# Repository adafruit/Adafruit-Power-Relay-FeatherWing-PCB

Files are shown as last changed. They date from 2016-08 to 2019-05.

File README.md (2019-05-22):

## Adafruit Power Relay FeatherWing PCB
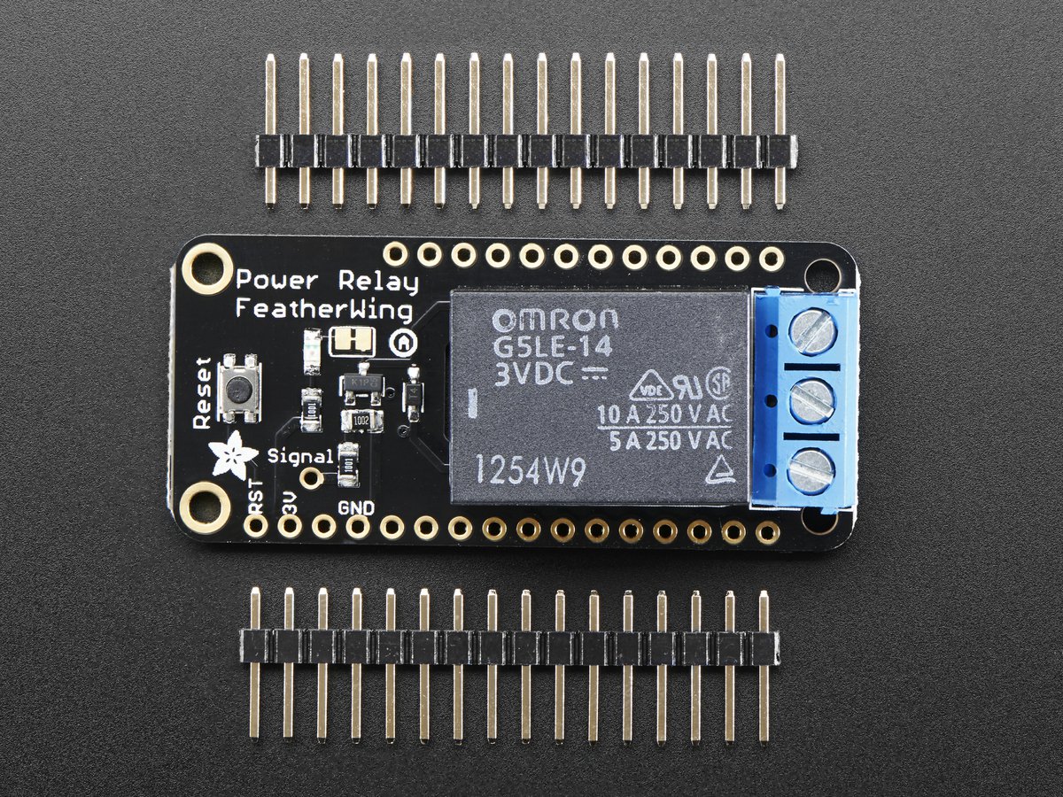
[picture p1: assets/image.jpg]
<a href="http://www.adafruit.com/products/3191"><br/>
Click here to purchase one from the Adafruit shop</a>

This is the Power Relay FeatherWing. It gives you power to control, and control over power. Put simply, you can now turn on and off lamps, fans, solenoids, and other small appliances that run on up to 250VAC or DC power using any Feather board. Compared to our smaller Relay FeatherWings, this one can handle a beefy 1200 Watts!

Works with all/any of our Feather boards, just wire up the relay control pin to whatever GPIO you like! Using our Feather Stacking Headers or Feather Female Headers you can connect a FeatherWing on top of your Feather board and let the board take flight. Check out our range of Feather boards here.

This Wing has a non-latching type relay. You can switch up to 10A of resistive-load current at 120VAC, 5A at 240VAC. With inductive loads, about half that. Check the datasheet for the relay for the exact switching capacity, as it depends on type of load and voltage type and magnitude. This relay is good for handling fairly large devices, computers, TVs, small appliances and more.

PCB files for the Adafruit Power Relay FeatherWing. The format is EagleCAD schematic and board layout
- https://www.adafruit.com/products/3191

### License

Adafruit invests time and resources providing this open source design, please support Adafruit and open-source hardware by purchasing products from [Adafruit](https://www.adafruit.com)!

All text above must be included in any redistribution

Designed by Limor Fried/Ladyada for Adafruit Industries.
Creative Commons Attribution/Share-Alike, all text above must be included in any redistribution. 
See license.txt for additional information.

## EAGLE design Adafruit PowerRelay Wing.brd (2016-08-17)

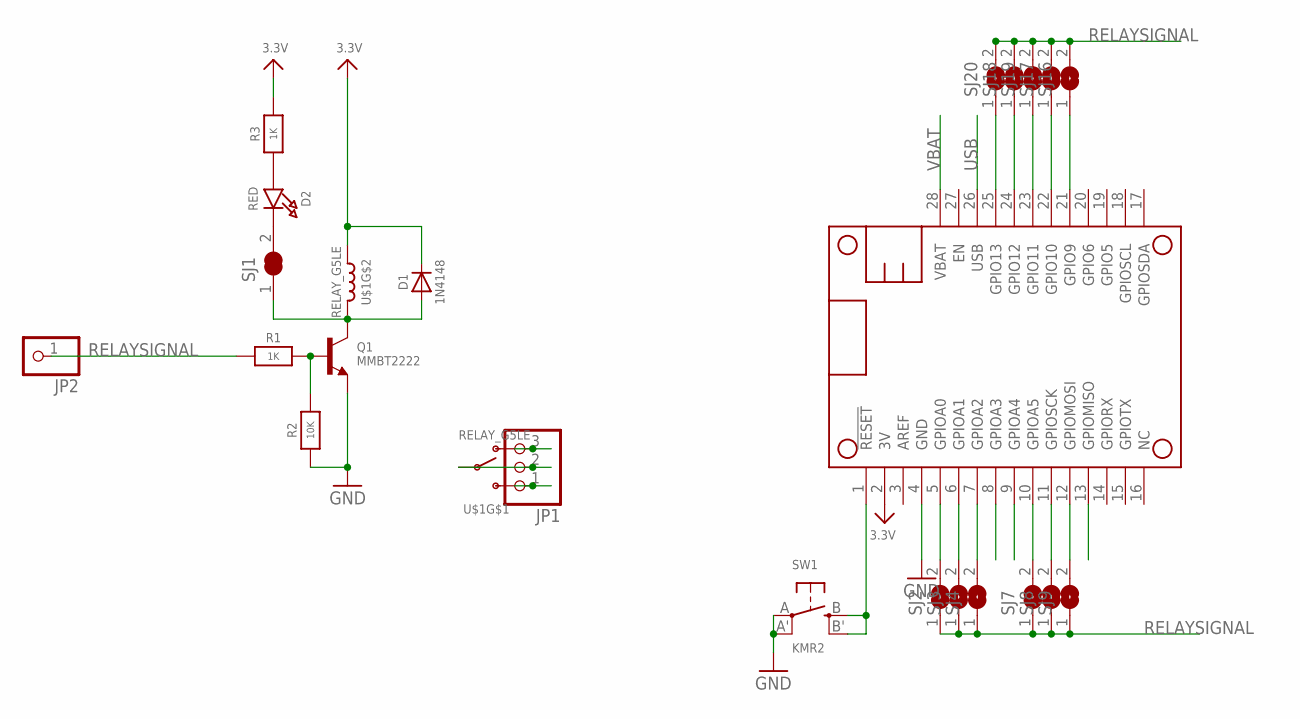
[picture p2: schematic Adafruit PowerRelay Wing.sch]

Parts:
D1: 1N4148; SOD-323
D2: RED; CHIPLED_0805_NOOUTLINE
JP1: HEADER-1X3_508TERM; TERMBLOCK_1X3_5.08MM
JP2: HEADER-1X1ROUND; 1X01_ROUND
MS2: FEATHERWING
Q1: MMBT2222; SOT23-R
R1, R3: 1K; 0805-NO
R2: 10K; 0805-NO
SJ1: SOLDERJUMPER_CLOSED; SOLDERJUMPER_CLOSEDWIRE
SJ2, SJ3, SJ4, SJ7, SJ8, SJ9, SJ16, SJ17, SJ18, SJ19, SJ20: SOLDERJUMPER; SOLDERJUMPER_ARROW_NOPASTE
SW1: KMR2; BTN_KMR2_4.6X2.8
U$1: RELAY_G5LE; RELAY_G5LE-1

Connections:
3.3V: D1.C, MS2.2 (3V), R3.2, U$1.2 (1)
GND: MS2.4 (GND), Q1.2 (E), R2.1, SW1.A, SW1.A' (P1)
unnamed: JP1.2, U$1.1
unnamed: JP1.3, U$1.3 (O)
unnamed: JP1.1, U$1.4 (S)
unnamed: D1.A, Q1.3 (C), SJ1.1, U$1.5 (2)
unnamed: MS2.12 (GPIOMOSI), SJ9.2
unnamed: MS2.11 (GPIOSCK), SJ8.2
unnamed: MS2.10 (GPIOA5), SJ7.2
unnamed: MS2.7 (GPIOA2), SJ4.2
unnamed: MS2.6 (GPIOA1), SJ3.2
unnamed: MS2.5 (GPIOA0), SJ2.2
unnamed: MS2.25 (GPIO13), SJ20.1
unnamed: MS2.24 (GPIO12), SJ18.1
unnamed: MS2.1 (!RESET), SW1.B (S), SW1.B' (S1)
unnamed: MS2.23 (GPIO11), SJ19.1
unnamed: MS2.22 (GPIO10), SJ17.1
unnamed: MS2.21 (GPIO9), SJ16.1
unnamed: Q1.1 (B), R1.2, R2.2
unnamed: D2.C, SJ1.2
unnamed: D2.A, R3.1
RELAYSIGNAL: JP2.1, R1.1, SJ2.1, SJ3.1, SJ4.1, SJ7.1, SJ8.1, SJ9.1, SJ16.2, SJ17.2, SJ18.2, SJ19.2, SJ20.2
USB: MS2.26 (USB)
VBAT: MS2.28 (VBAT)

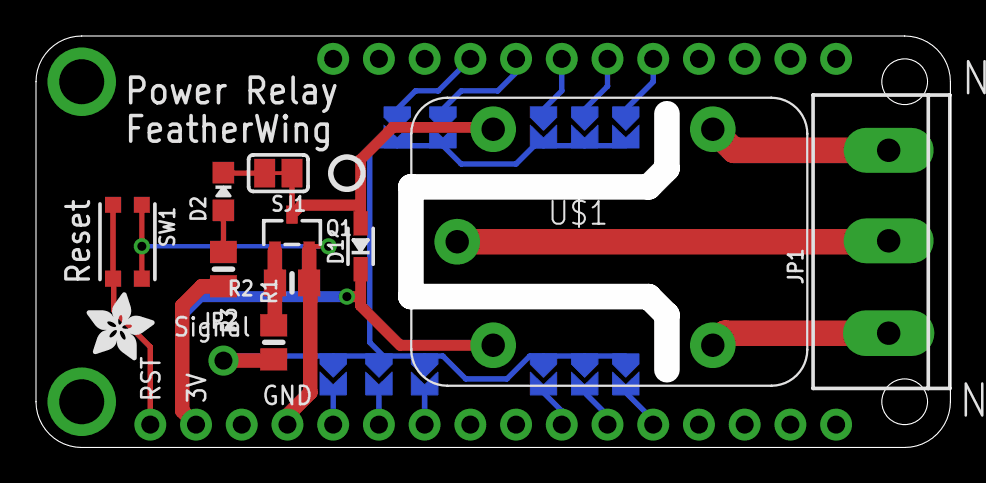
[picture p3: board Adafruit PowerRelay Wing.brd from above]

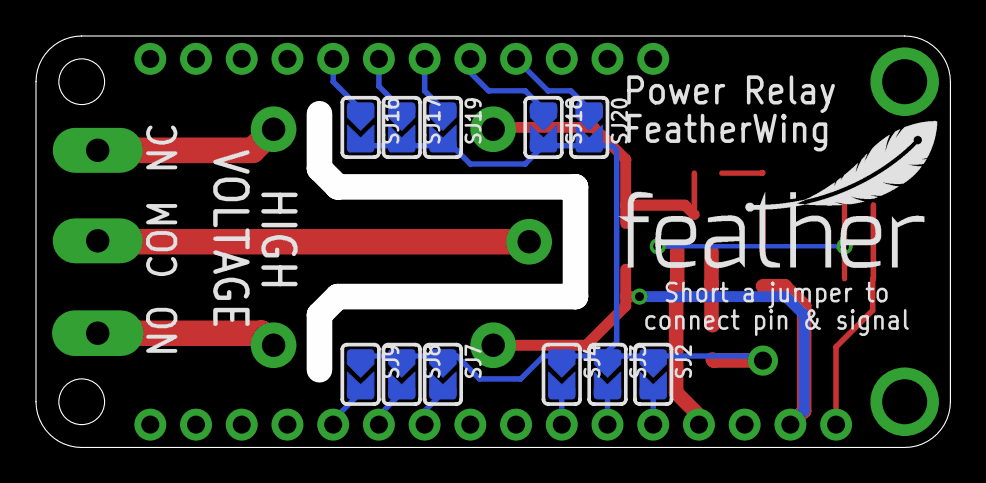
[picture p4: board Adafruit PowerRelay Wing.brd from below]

Board: 2 copper layers, 50.8 x 22.9 mm, 26 parts (12 on the bottom side), 22 nets.

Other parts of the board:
U$5: PCBFEAT-REV-040
U$6: ADAFRUIT_3.5MM
U$7: FEATHERLOGO_MED

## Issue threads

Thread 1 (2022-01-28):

Forces Adalogger M0 into bootloader mode

treychaffin, 2022-01-28:
I am using the Power Relay FeatherWing stacked on top of a Feather M0 Adalogger. I have a 120 VAC, 13 watt incandescent lightbulb connected to the normally side of the relay. I have the relay set up to be triggered with the A1 pin on the Adalogger. I'm using a simple arduino sketch to toggle the relay using Serial.read and keyboard commands. Toggling the relay will randomly (every 2-6 toggles) send the Adalogger into bootloader mode, it doesn't seem to matter whether or not the relay is being toggled on or off. When no load is attached to the relay, the relay functions correctly and doesn't randomly send the Adalogger into bootloader mode.

I've used a variety of lightbulbs, incandescants, CFLs, and LEDs, all of which this problem is repeatable. I've tried using spare relay and Adalogger modules, the problem is still repeatable.

ladyada, 2022-01-28:
hiya, questions about how to use adafruit products are best posted in the adafruit forums  at [forums.adafruit.com](forums.adafruit.com/)
thats where tech support is handled - github issues are where folks can issue bug reports (e.g. something that ought to work but doesnt due to a hardware or software bug)

thanks! :)

Closed 2022-01-28.

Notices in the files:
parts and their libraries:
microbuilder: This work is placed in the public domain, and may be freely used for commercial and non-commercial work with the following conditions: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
